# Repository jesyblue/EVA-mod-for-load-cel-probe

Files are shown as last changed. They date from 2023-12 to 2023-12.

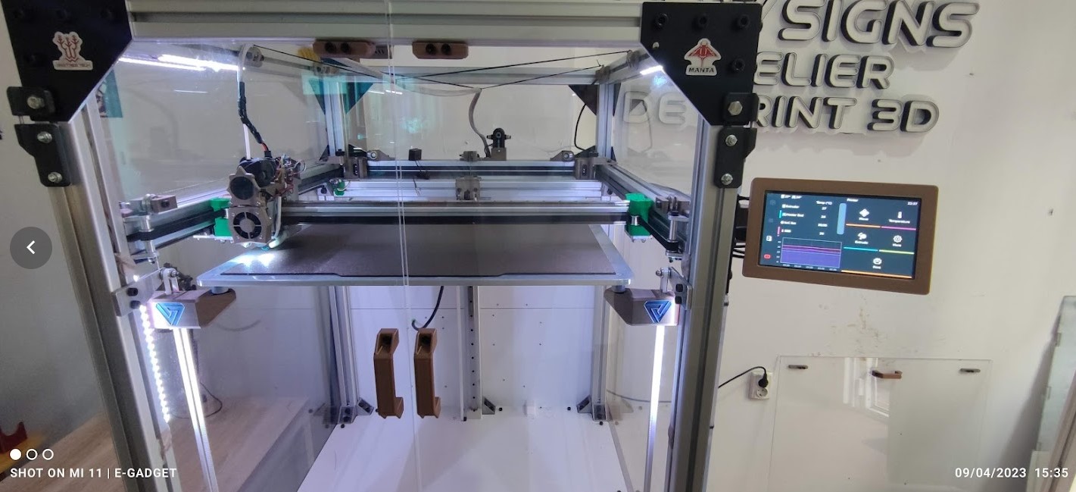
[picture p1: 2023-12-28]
img/screen1.jpg

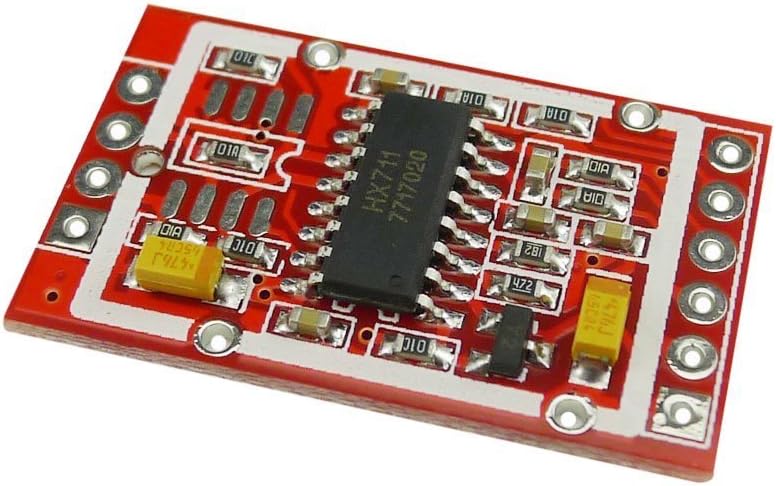
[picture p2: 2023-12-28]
img/61+0v47EAHL._AC_SL1200_.jpg

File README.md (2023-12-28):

# EVA-mod-for-load-cell-probe

Mod for EVA 3.0  toolhead from RatRig to use a Load Cell for probing the bed

On my new project of a 3D printer with a 500x500x500 print area , inspired by V-core 3.1 from RatRig i had to implement some changes to meet my needs. 

Of course, I end up to change almost every component design from the original project.  

In this repository I want to share my implementation of a normal load cell in the toolhead to allow me a quick and precise bed mesh and bed probing. 

toolhead_1

screen1

I chose to use two 12mm linear rail mounted on a 20x20mm aluminum extrusion with two MGN12HZ0HM linear bearing mounted on toolhead. 

toolhead_2

the toolhead have fallowing components >

- LGX Lite Extruder V2 by Bondtech
- Hotend CHC V6 24V
- BIGTREETECH EBB36 V1.2 (on canbus)
- BIGTREETECH KNOMI V1.0

My approach was to use a separate microcontroller to manage the load cell. All what was needed is 

a normal load cell for 5kg with HX711 board.    
 
load cel

and a Arduino Pro Micro (Mega 32U4)
Arduino Pro Micro

The firmware which i made in Visuino must manage the HX711 to his maximum sample rate of 80Hz.  I had to change the board which come with load cell with the green version , this allow me to change the sample rate from 10Hz to 80 Hz putting to VCC pin 15. explained very well here instructables.com/How-to-Convert-Your-HX-711-Board-From-10Hz-to-80Hz

hx711
HX711_mod

this is a section view of the toolhead:

toolhead_3

this is the force path:

toolhead_4

i had to cut about 12,5mm from each end of the load cell to fit inside the toolhead.

cell_cut_2

cell_mount_2

this is a early test when the code was not fast enough

https://photos.app.goo.gl/1WQfbn4UWSj5rhDH8

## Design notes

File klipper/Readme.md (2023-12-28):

In klipper what is important is to define probe section and the activation pin 

 ```yaml
[output_pin probe_0]
pin: EBBCan:PB9
#pwm: False
#static_value:
value: 0
#shutdown_value:
#maximum_mcu_duration:
#cycle_time: 0.100
#hardware_pwm: False
#scale:

[probe]
pin: EBBCan:PB8
speed: 2
samples: 1
z_offset: 0.5
sample_retract_dist: 5
lift_speed: 2
samples_result: median
samples_tolerance: 0.1
samples_tolerance_retries: 2
activate_gcode:
  G4 P500 #pause
  SET_PIN PIN=probe_0 VALUE=1
  G4 P500 #pause
  SET_PIN PIN=probe_0 VALUE=0
  G4 P500 #pause
  SET_PIN PIN=probe_0 VALUE=1
  SET_LED LED=hotend_rgb RED=1.0 GREEN=1.0 BLUE=0.0
deactivate_gcode:
  SET_PIN PIN=probe_0 VALUE=0
  SET_LED LED=hotend_rgb RED=1.0 GREEN=1.0 BLUE=1.0
 # G4 P500 #pause
 ```

Ad some macro for activate and deactivate the probe.

```yaml
[gcode_macro Enable_probe]
gcode:
  G4 P500 #pause
  SET_PIN PIN=probe_0 VALUE=1
  G4 P500 #pause
  SET_PIN PIN=probe_0 VALUE=0
  G4 P500 #pause
  SET_PIN PIN=probe_0 VALUE=1
  SET_LED LED=hotend_rgb RED=1.0 GREEN=1.0 BLUE=0.0

[gcode_macro disable_probe]
gcode:
  SET_PIN PIN=probe_0 VALUE=0
  SET_LED LED=hotend_rgb RED=1.0 GREEN=1.0 BLUE=1.0
 # G4 P500 #pause
 ```

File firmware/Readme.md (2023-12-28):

The code was made in Visuino, i have two versions, one with a OLED display for debug purpose , another one just the code to emulate a probe in klipper.   

The load cell don’t need to calibrate or anything…  just activate the HX711 before probe , reset and wait to probe.  When probe touch the bed will hear a sound on the buzzer (use a active buzzer, don’t need to be driven by code) and send positive probe to klipper. “that's it and that's all”

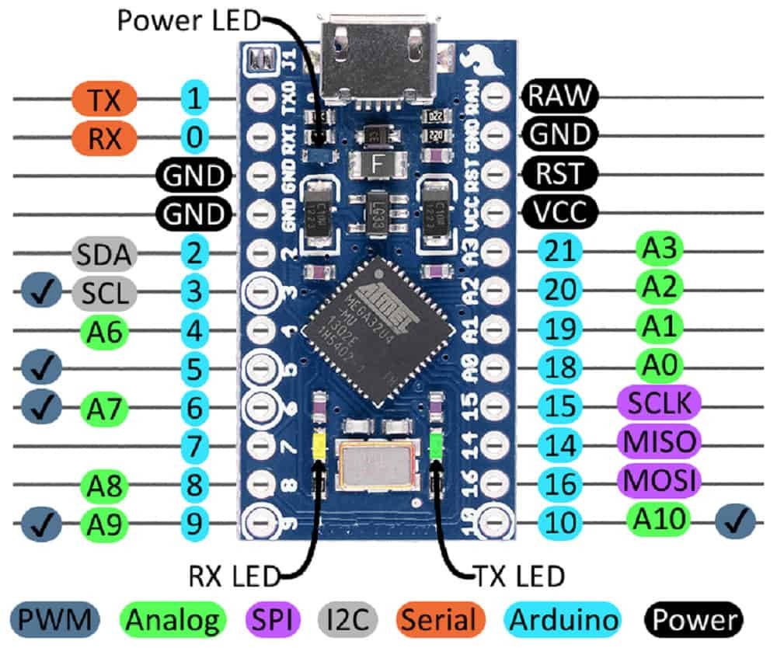
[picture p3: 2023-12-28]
img/pro_micro_5v_2_jpg.jpeg

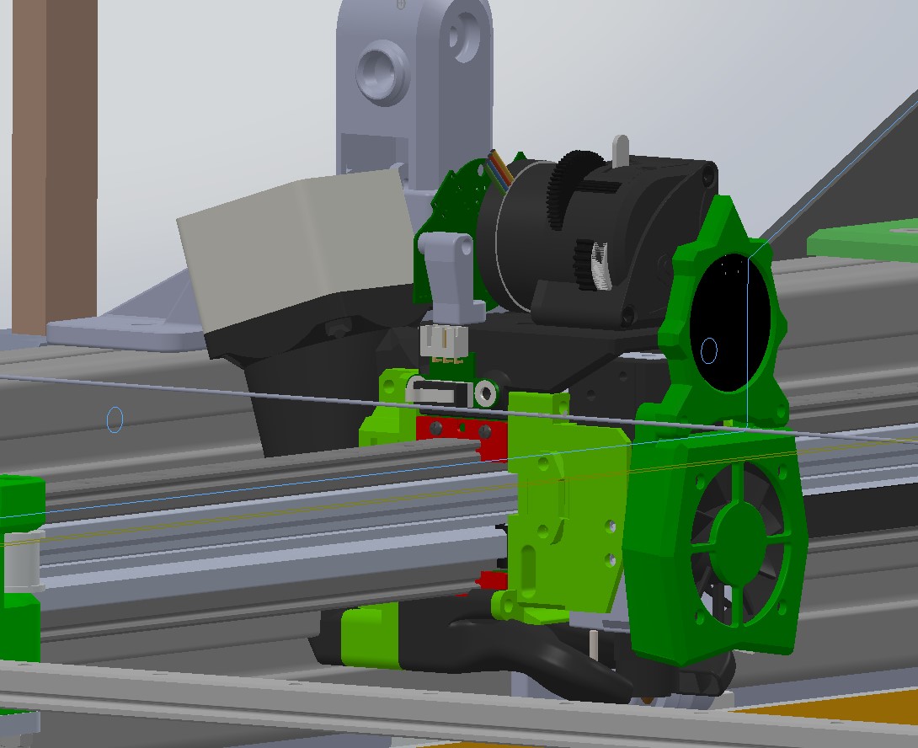
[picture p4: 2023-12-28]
img/toolhead_2.jpg

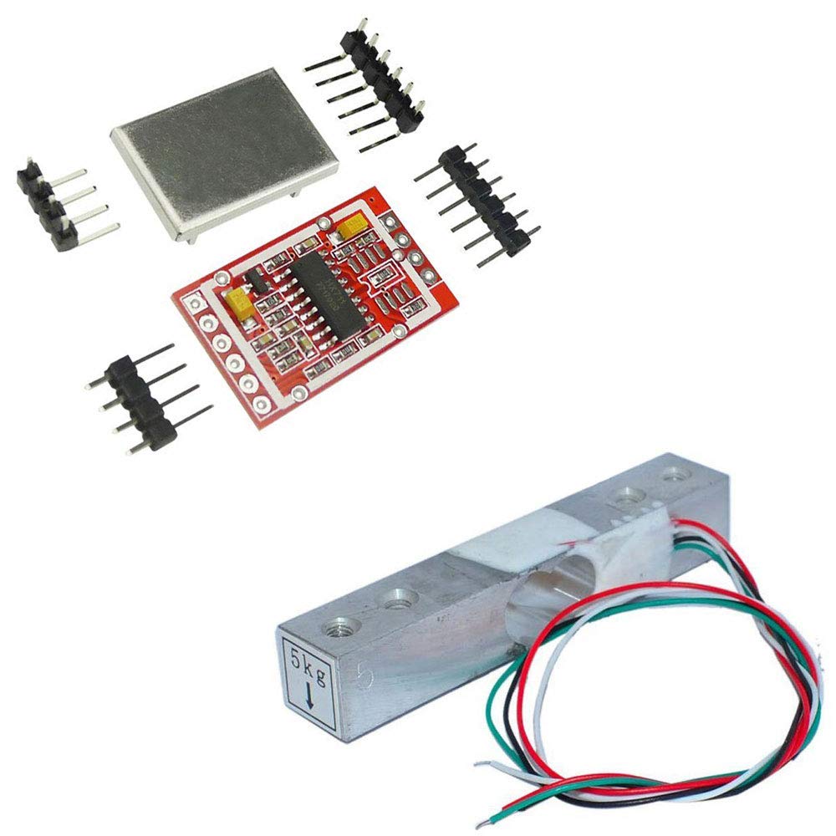
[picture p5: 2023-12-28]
img/load cel.jpg

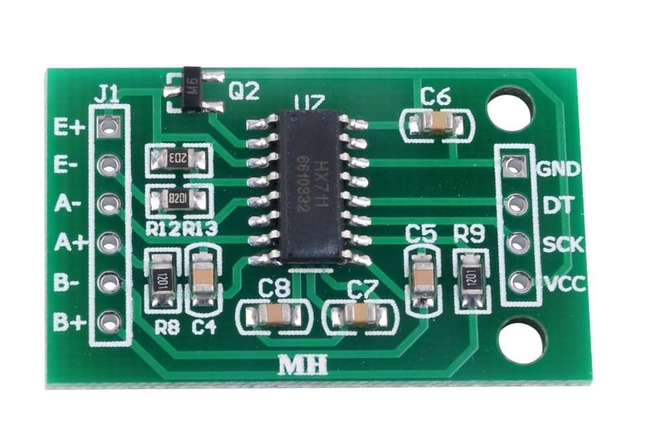
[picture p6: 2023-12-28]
img/hx711.jpg

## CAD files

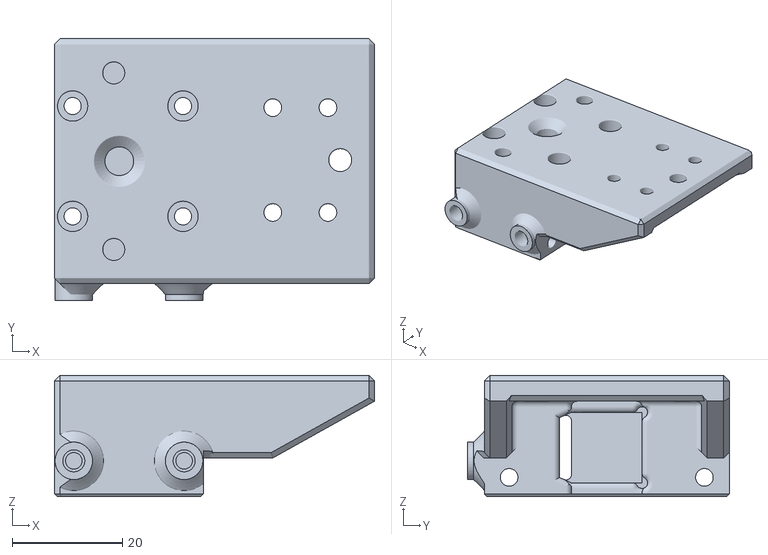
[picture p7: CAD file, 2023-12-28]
Hardware/STL/Load_cell_mount_V2.STL
58.0 x 47.4 x 22.0

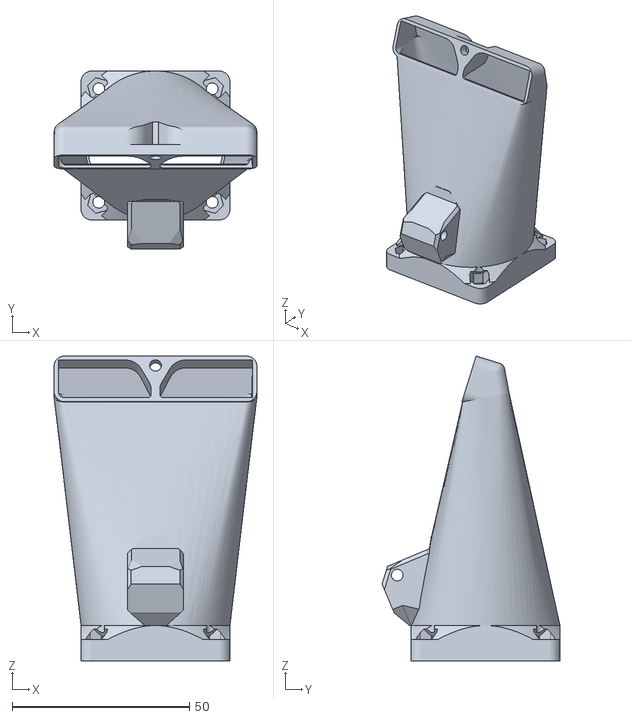
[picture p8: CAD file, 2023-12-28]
Hardware/STL/40mm_fan_inlet.STL
57.2 x 50.2 x 86.0

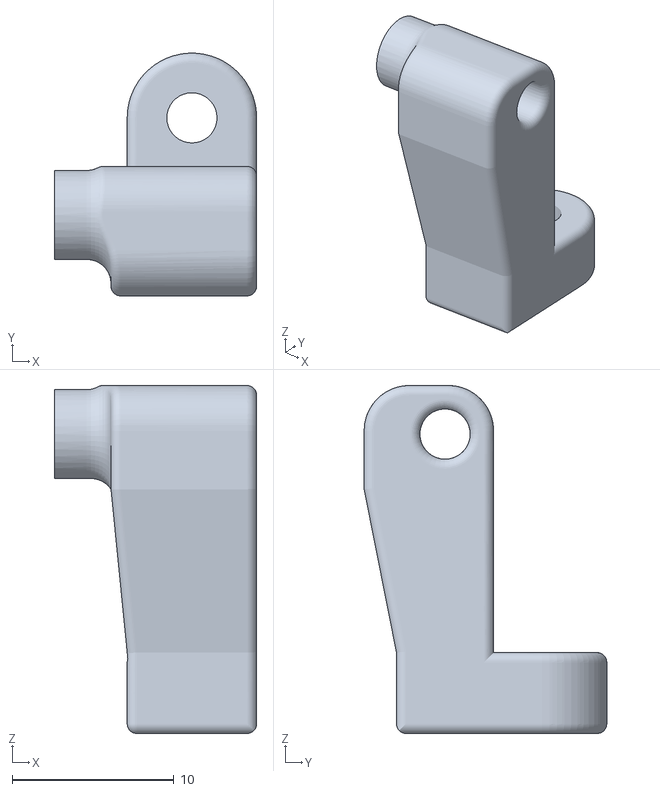
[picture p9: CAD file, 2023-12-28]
Hardware/STL/EEB_SUPORT.STL
12.5 x 15.0 x 21.5

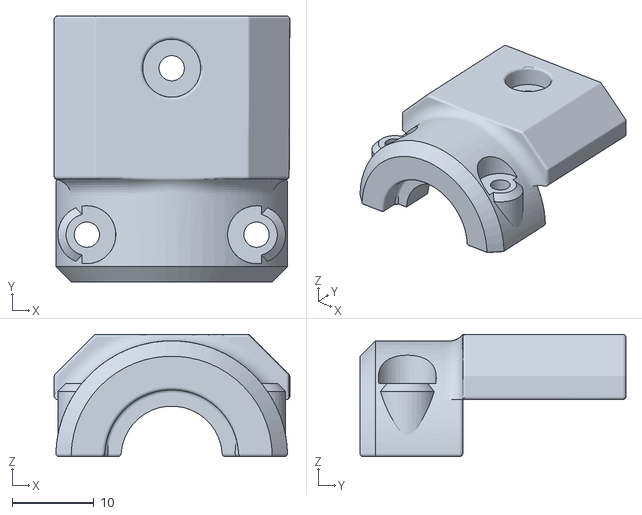
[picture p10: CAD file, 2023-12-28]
Hardware/STL/V6_holder_front.STL
28.9 x 32.6 x 15.0

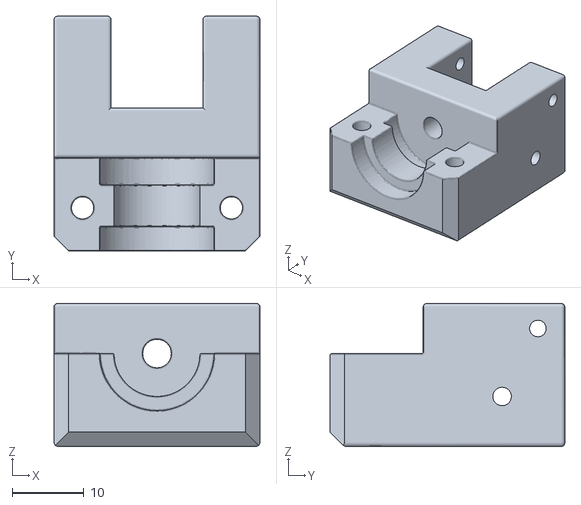
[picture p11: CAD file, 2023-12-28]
Hardware/STL/V6_holder.STL
28.8 x 32.8 x 20.0

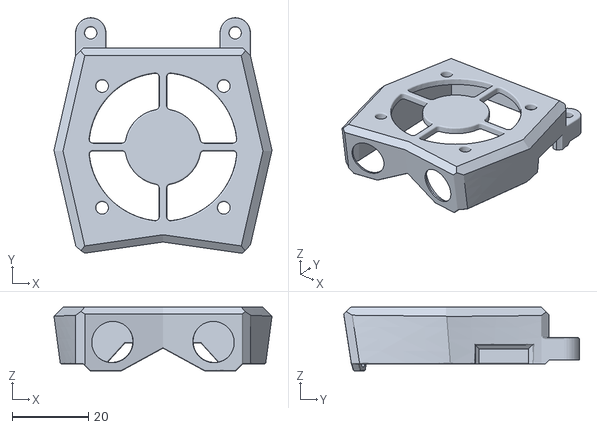
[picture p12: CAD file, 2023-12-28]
Hardware/STL/FRONT_COVER_eva.STL
57.3 x 62.0 x 16.8

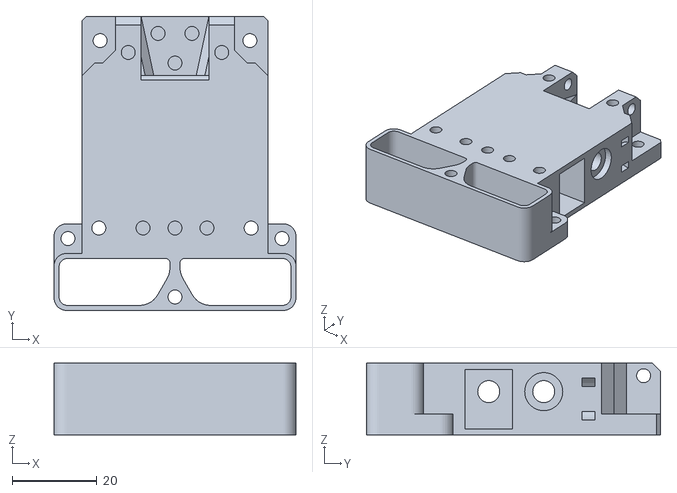
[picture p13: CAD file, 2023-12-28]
Hardware/STL/back_core_xy.STL
57.2 x 69.5 x 17.0

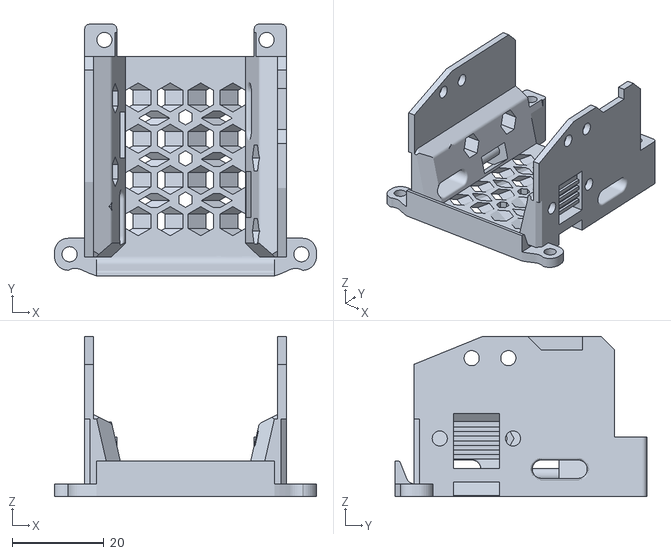
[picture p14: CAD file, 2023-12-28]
Hardware/STL/front_universal.STL
57.2 x 54.9 x 35.0

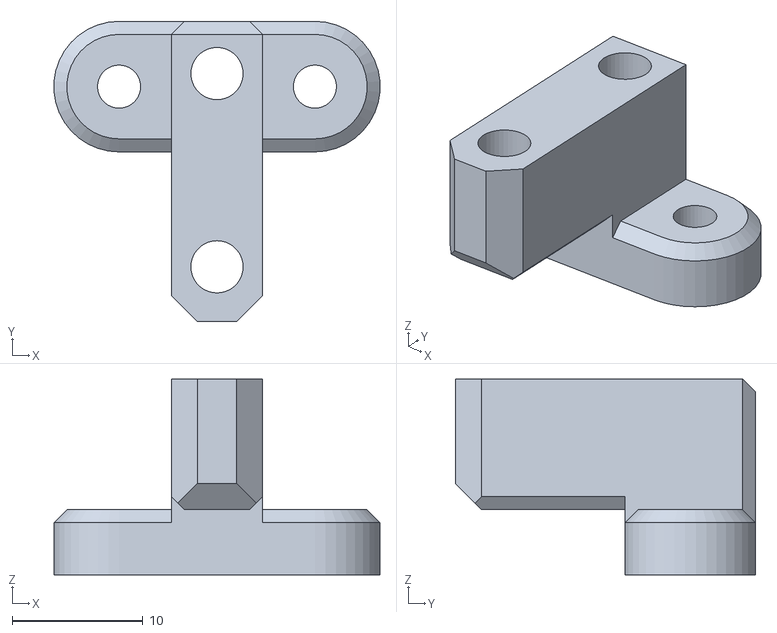
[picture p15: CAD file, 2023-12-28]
Hardware/STL/suport_clip_cabluri.STL
25.0 x 23.0 x 15.0

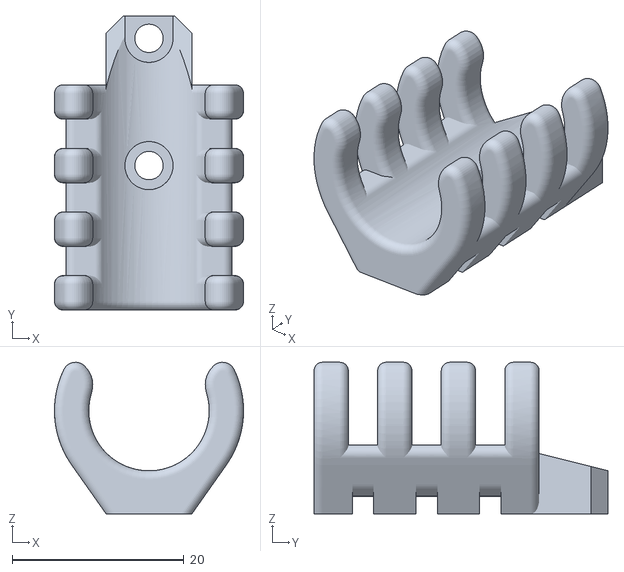
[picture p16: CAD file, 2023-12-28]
Hardware/STL/cable_guide.STL
22.0 x 34.2 x 17.6

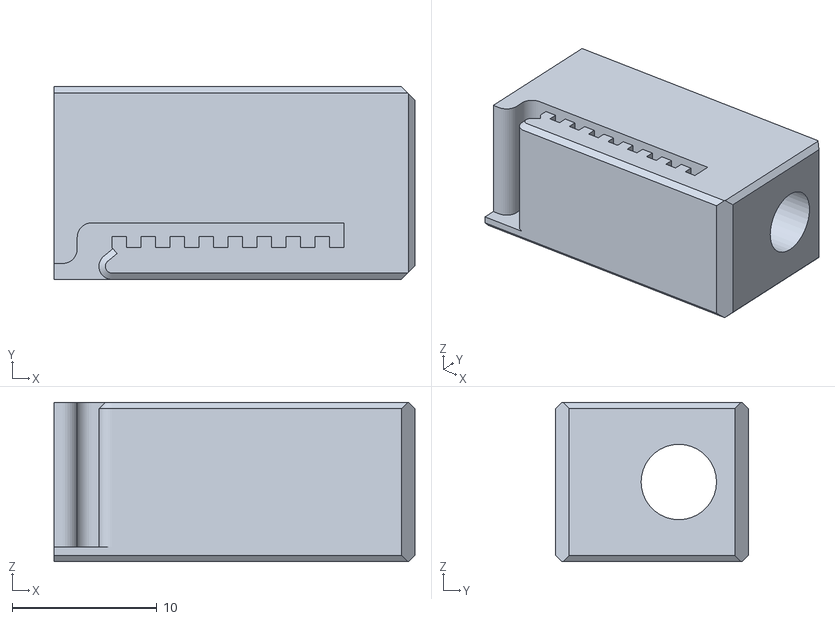
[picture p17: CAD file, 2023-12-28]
Hardware/STL/core_xy_belt_grabber x2.STL
24.9 x 13.3 x 11.0

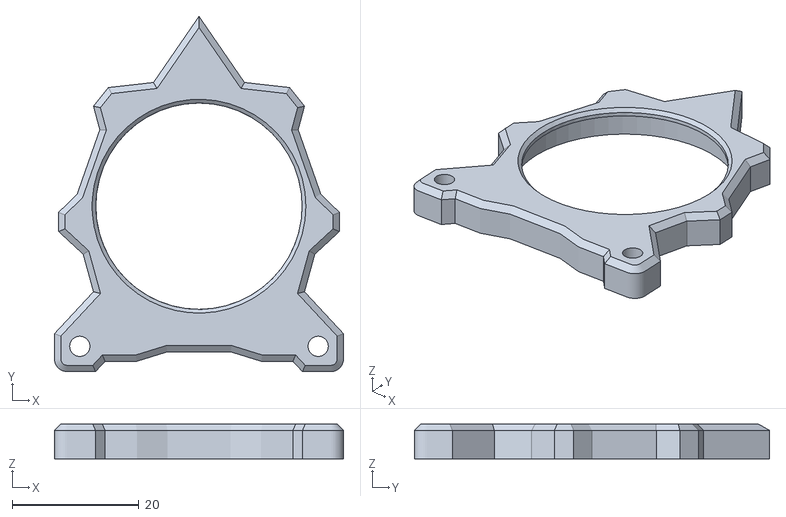
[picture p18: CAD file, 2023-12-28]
Hardware/STL/Knomi_mount.STL
45.7 x 56.1 x 5.50

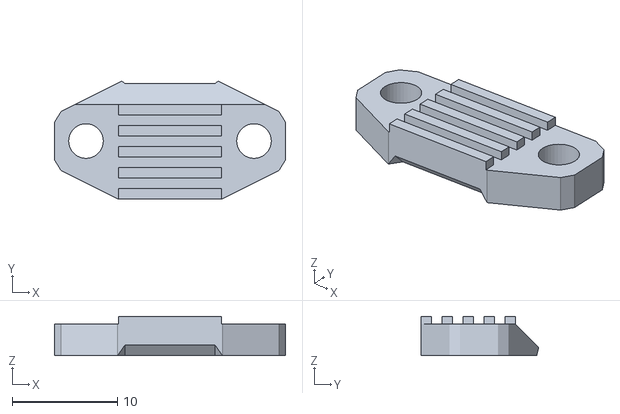
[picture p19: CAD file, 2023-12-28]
Hardware/STL/face_belt_grabber x2.STL
22.0 x 11.2 x 3.75

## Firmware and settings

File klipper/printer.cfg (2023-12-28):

[include mainsail.cfg]

# host MCU service is preinstalled and ready to use with:

[include ebb-canbus-v1.1.cfg]
[include manta-m5p.cfg]
[include timelapse.cfg]
[include leds.cfg]

[display_status]

[gcode_macro _CLIENT_VARIABLE]
variable_use_custom_pos   : True ; use custom park coordinates for x,y [True/False]
variable_custom_park_x    : 20.0   ; custom x position; value must be within your defined min and max of X
variable_custom_park_y    : 20.0   ; custom y position; value must be within your defined min and max of Y
variable_custom_park_dz   : 3.0   ; custom dz value; the value in mm to lift the nozzle when move to park position
variable_retract          : 1.0   ; the value to retract while PAUSE
variable_cancel_retract   : 3.0   ; the value to retract while CANCEL_PRINT
variable_speed_retract    : 50.0  ; retract speed in mm/s
variable_unretract        : 1.0   ; the value to unretract while RESUME
#variable_speed_unretract  : 35.0  ; unretract speed in mm/s
#variable_speed_hop        : 15.0  ; z move speed in mm/s
#variable_speed_move       : 100.0 ; move speed in mm/s
variable_park_at_cancel   : True ; allow to move the toolhead to park while execute CANCEL_PRINT [True/False]
variable_park_at_cancel_x : 10  ; different park position during CANCEL_PRINT [None/Position as Float]; park_at_cancel must be True
variable_park_at_cancel_y : 10  ; different park position during CANCEL_PRINT [None/Position as Float]; park_at_cancel must be True
## !!! Caution [firmware_retraction] must be defined in the printer.cfg if you set use_fw_retract: True !!!
#variable_use_fw_retract   : False ; use fw_retraction instead of the manual version [True/False]
#variable_idle_timeout     : 0     ; time in sec until idle_timeout kicks in. Value 0 means that no value will be set or restored
gcode:

[force_move]
enable_force_move: true
#   Set to true to enable FORCE_MOVE and SET_KINEMATIC_POSITION
#   extended G-Code commands. The default is false.

[z_tilt]
##  Use Z_TILT_ADJUST to level the bed .
##  z_positions: Location of toolhead

z_positions:
	500,0
	255,500
	0,0

points:
	470,50
	255,460
	50,50

speed: 100
horizontal_move_z: 5
retries: 5
retry_tolerance: 0.2

[homing_override]
gcode:
    G90 ; Use absolute position mode
    G1 Z5 ; Move up 10mm
    G28 X Y
    G1 X255 Y255 F5000 ; Change the X and Y coordinates to the center of your print bed
    G28 Z
    G1 Z6 F5000
    Z_TILT_ADJUST
    G1 X255 Y255 F5000 ; Change the X and Y coordinates to the center of your print bed
set_position_z: 0.0

[bed_mesh]
speed: 120
horizontal_move_z: 5
mesh_min: 40, 40
mesh_max: 460, 460
probe_count: 6, 6

[filament_motion_sensor SFS_T0]
detection_length: 75.00 ; This can be adjusted to your desired level of sensitivity. 10 is a recomended value to prevent flow dropoff false triggers.
extruder: extruder
switch_pin: ^PC15
pause_on_runout: True ; This can be set to false to debug false positives putting the sensor in "monitor mode". The printer will not pause but it will run the runout_gcode below. 
event_delay: 15.0
#pause_delay: 0.5
runout_gcode:
    M117 Runout Detected!

[delayed_gcode DISABLEFILAMENTSENSOR] ; This will disable the SFS 1 second after klipper starts
initial_duration: 1
gcode:
    SET_FILAMENT_SENSOR SENSOR=SFS_T0 ENABLE=0 ; Put your filament sensor's name after SENSOR=

[gcode_macro SFS_ENABLE] ; Add this to PRINT_START
description: Enable smart filament sensor
gcode:
    M117 ENABLING the Smart Filament Sensor
    G92 E0
    SET_FILAMENT_SENSOR SENSOR=SFS_T0 ENABLE=1 ; Put your filament sensor's name after SENSOR=

[gcode_macro SFS_DISABLE] ; Add this to PRINT_END and PRINT_CANCEL
description: Disable smart filament sensor 
gcode:
    M117 DISABLING the Smart Filament Sensor
    G92 E0
    SET_FILAMENT_SENSOR SENSOR=SFS_T0 ENABLE=0 ; Put your filament sensor's name after SENSOR=

[input_shaper]
shaper_freq_x: 63.2
shaper_freq_y: 30.6
#shaper_type: mzv
shaper_type_x: 2hump_ei
shaper_type_y: zv
#damping_ratio_x: 0.1
#damping_ratio_y: 0.1

[resonance_tester]
accel_chip: adxl345
probe_points:
    250,250,20 

[gcode_macro Enable_probe]
gcode:
  G4 P500 #pause
  SET_PIN PIN=probe_0 VALUE=1
  G4 P500 #pause
  SET_PIN PIN=probe_0 VALUE=0
  G4 P500 #pause
  SET_PIN PIN=probe_0 VALUE=1
  SET_LED LED=hotend_rgb RED=1.0 GREEN=1.0 BLUE=0.0

[gcode_macro disable_probe]
gcode:
  SET_PIN PIN=probe_0 VALUE=0
  SET_LED LED=hotend_rgb RED=1.0 GREEN=1.0 BLUE=1.0
 # G4 P500 #pause

[gcode_macro SENSORLESS_HOME_Z]
gcode:
    {% set HOME_CUR = 0.500 %}
    {% set driver_config = printer.configfile.settings['tmc2209 stepper_z'] %}
    {% set RUN_CUR = driver_config.run_current %}
    # Set current for sensorless homing
    SET_TMC_CURRENT STEPPER=stepper_z CURRENT={HOME_CUR}
    SET_TMC_CURRENT STEPPER=stepper_z1 CURRENT={HOME_CUR}
    SET_TMC_CURRENT STEPPER=stepper_z2 CURRENT={HOME_CUR}
    # Pause to ensure driver stall flag is clear
    G4 P2000
    # Home
    G28 Z0
    # Move away
    G90
    G1 Z5 F4000
    # Set current during print
    SET_TMC_CURRENT STEPPER=stepper_z CURRENT={RUN_CUR}
    SET_TMC_CURRENT STEPPER=stepper_z1 CURRENT={RUN_CUR}
    SET_TMC_CURRENT STEPPER=stepper_z2 CURRENT={RUN_CUR}

[gcode_macro UNSAFE_XY_test]
description: move XY without homing
gcode:
  G90
  SET_KINEMATIC_POSITION Z=0
  G0 Y400 X400 F8000
  G0 Y50 X50 
  G0 Y400 X400 
  G0 Y50 X50 
  M84


[gcode_macro UNSAFE_X_test]
description: move X without homing
gcode:
  G90
  SET_KINEMATIC_POSITION Z=0
  G0  X400 F8000
  G0  X50 
  G0  X400 
  G0  X50 
  M84


[gcode_macro  SET_KINEMATIC]
description: unlook move without homing
gcode:
  
  SET_KINEMATIC_POSITION Z=0
### Modify M73 ###

[gcode_macro M73]
rename_existing: M73.1
variable_p: 0.0
variable_r: 0.0
gcode:
   {% set P = params.P|default(0)|int %}
   {% set R = params.R|default(0)|int %}
   M73.1 P{P}
   SET_GCODE_VARIABLE MACRO=M73 VARIABLE=p VALUE={P}
   SET_GCODE_VARIABLE MACRO=M73 VARIABLE=r VALUE={R}


[display_template _printing_time]
text:
   {% set ptime = printer["gcode_macro M73"].r %}
   { "%02d:%02d" % (ptime // 60, ptime % 60) }

[idle_timeout]
gcode:
  {% if printer.pause_resume.is_paused %}
  M104 S0# Set Hot-end to 0C (off)
  RESPOND PREFIX=tgalarm MSG="Print is paused - Idle timeout disabled"
  M117 "Print is paused - Idle timeout disabled"
  {% else %}
  TURN_OFF_HEATERS
  M84
  SET_LED LED=pixels_R RED=0.0 GREEN=0.5 BLUE=0.2
  SET_LED LED=pixels_L RED=0.0 GREEN=0.5 BLUE=0.2
  SET_LED LED=hotend_rgb RED=0.0 GREEN=0.2 BLUE=0.2
  M117 "Shutting down..."
  {% endif %}
timeout: 600
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

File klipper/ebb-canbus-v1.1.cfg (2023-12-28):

# This file contains common pin mappings for the BIGTREETECH EBBCan
# Canbus board. To use this config, the firmware should be compiled for the
# STM32G0B1 with "8 MHz crystal" and "USB (on PA11/PA12)" or "CAN bus (on PB0/PB1)".
# The "EBB Can" micro-controller will be used to control the components on the nozzle.

# See docs/Config_Reference.md for a description of parameters.

[mcu EBBCan]
#serial: /dev/serial/by-id/usb-Klipper_Klipper_firmware_12345-if00
canbus_uuid: 7d8b4a64f2f1

[adxl345]
cs_pin: EBBCan:PB12
spi_software_sclk_pin: EBBCan:PB10
spi_software_mosi_pin: EBBCan:PB11
spi_software_miso_pin: EBBCan:PB2
axes_map: x,z,y

[extruder]
step_pin: EBBCan:PD0
dir_pin: !EBBCan:PD1
enable_pin: !EBBCan:PD2
microsteps: 32
nozzle_diameter: 0.400
rotation_distance: 5.7
full_steps_per_rotation: 200
filament_diameter: 1.750
max_extrude_only_velocity: 120
max_extrude_only_accel: 800
pressure_advance_smooth_time: 0.02
heater_pin: EBBCan:PB13
sensor_type: EPCOS 100K B57560G104F
sensor_pin: EBBCan:PA3
control: pid
pid_Kp: 25.763
pid_Ki: 1.561
pid_Kd: 106.274
min_temp: 0
max_temp: 270

[firmware_retraction]
retract_speed: 120
unretract_extra_length: 0
unretract_speed: 120


[tmc2209 extruder]
uart_pin: EBBCan: PA15
interpolate: false
run_current: 0.600
stealthchop_threshold: 999999
hold_current: 0.200
sense_resistor: 0.11
driver_TOFF: 4
driver_HSTRT: 7
driver_HEND: 6
driver_TBL: 0

[fan]
pin: EBBCan:PA1
# max_power: 0.6

[heater_fan hotend_fan]
pin: EBBCan:PA0
heater: extruder
heater_temp: 50.0


[output_pin probe_0]
pin: EBBCan:PB9
#pwm: False
#static_value:
value: 0
#shutdown_value:
#maximum_mcu_duration:
#cycle_time: 0.100
#hardware_pwm: False
#scale:

[probe]
pin: EBBCan:PB8
speed: 2
samples: 1
z_offset: 0.6
sample_retract_dist: 5
lift_speed: 2
samples_result: median
samples_tolerance: 0.1
samples_tolerance_retries: 2
activate_gcode:
  G4 P500 #pause
  SET_PIN PIN=probe_0 VALUE=1
  G4 P500 #pause
  SET_PIN PIN=probe_0 VALUE=0
  G4 P500 #pause
  SET_PIN PIN=probe_0 VALUE=1
  SET_LED LED=hotend_rgb RED=1.0 GREEN=1.0 BLUE=0.0
deactivate_gcode:
  SET_PIN PIN=probe_0 VALUE=0
  SET_LED LED=hotend_rgb RED=1.0 GREEN=1.0 BLUE=1.0
 # G4 P500 #pause





#[filament_switch_sensor switch_sensor]
#switch_pin: EBBCan:PB4

#[filament_motion_sensor motion_sensor]
#switch_pin: ^EBBCan:PB3
